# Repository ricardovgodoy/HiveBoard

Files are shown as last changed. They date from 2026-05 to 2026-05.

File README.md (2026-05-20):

# HiveBoard – a Modular Dexterity Benchmark for Industrial Robotics

<p align="center">
    <picture>
  <source media="(prefers-color-scheme: dark)" srcset="Images/HIVEBOARD_logo_dark.png" width="50%">
  <source media="(prefers-color-scheme: light)" srcset="Images/HIVEBOARD_logo_light.png" width="50%">
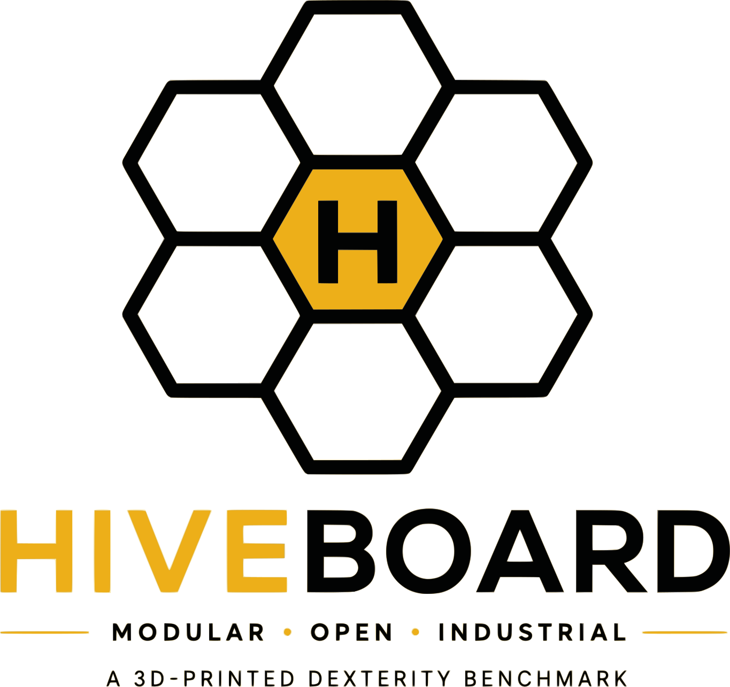
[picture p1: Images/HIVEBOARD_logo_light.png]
Project Logo
  
    </picture>
</p>

Demonstration video: https://youtu.be/kaYB_Oc64nA

## Overview

HiveBoard is an open, modular, and fully 3D-printable dexterity benchmark designed for evaluating industrial robotic manipulation systems. The project focuses on reproducibility, accessibility, and compatibility with both real-world robotic systems and simulation environments.

The platform is designed around three principles:

- **Low-cost reproducibility** using consumer-grade FDM 3D printers
- **Modular task expansion** through interchangeable attachments
- **Simulation-ready assets** for robotics research and sim-to-real workflows

The system consists of a **hexagonal honeycomb base** that accepts interchangeable attachments representing industrial manipulation tasks such as:

- Valves
- Circuit breakers
- Threaded fasteners
- Peg insertion
- Drawer manipulation
- Lock-and-key
- Shock absorber assemblies

All components in this repository are printable in **PLA filament**.

---

## Project Architecture

<p align="center">
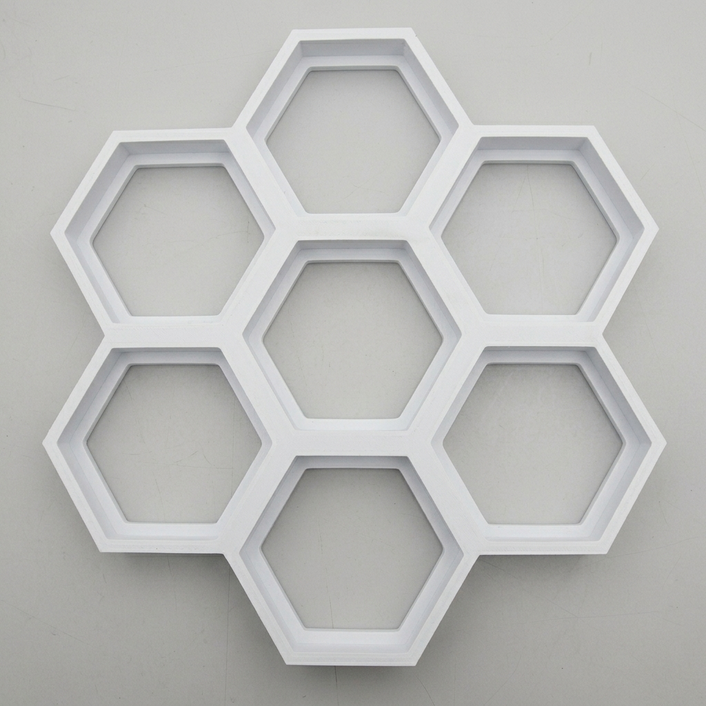
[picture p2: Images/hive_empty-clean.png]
    
</p>

The HiveBoard base contains seven hexagonal cells arranged in a honeycomb pattern. Each attachment uses a standardized press-fit mounting geometry, allowing rapid reconfiguration without screws or fasteners.

This modular architecture enables:

- Fast task swapping
- Difficulty scaling
- Multi-task robotic evaluations
- Easy extension with new attachments

---

## Attachment Categories

### 1. Torque-Based Tasks

<p align="center">
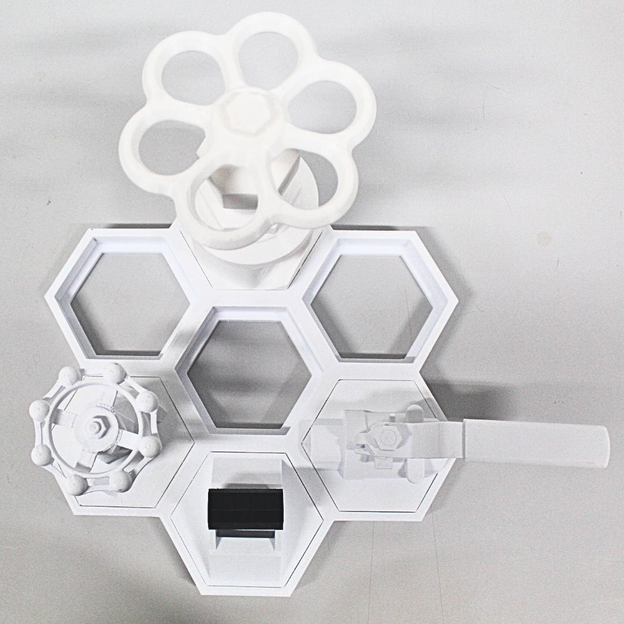
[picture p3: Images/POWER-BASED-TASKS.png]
    
</p>

These tasks evaluate force control and rotational manipulation capabilities.

Included components:

| Attachment | Description |
|---|---|
| Ball Valve | Quarter-turn valve with a lever handle |
| Friction Rings | Snap-on rings (set of four) that increase rotational friction, and therefore torque resistance, on the ball valve |
| Gate Valve (Small) | Compact gate valve with a smaller handwheel |
| Gate Valve (Large) | Larger gate valve with a higher-leverage handwheel |
| Circuit Breaker | Toggle-style industrial breaker |

The friction-ring system gives multiple torque levels on the ball valve without printing additional valves. Each ring sets a different rotational friction.

---

### 2. Precision-Based Tasks

<p align="center">
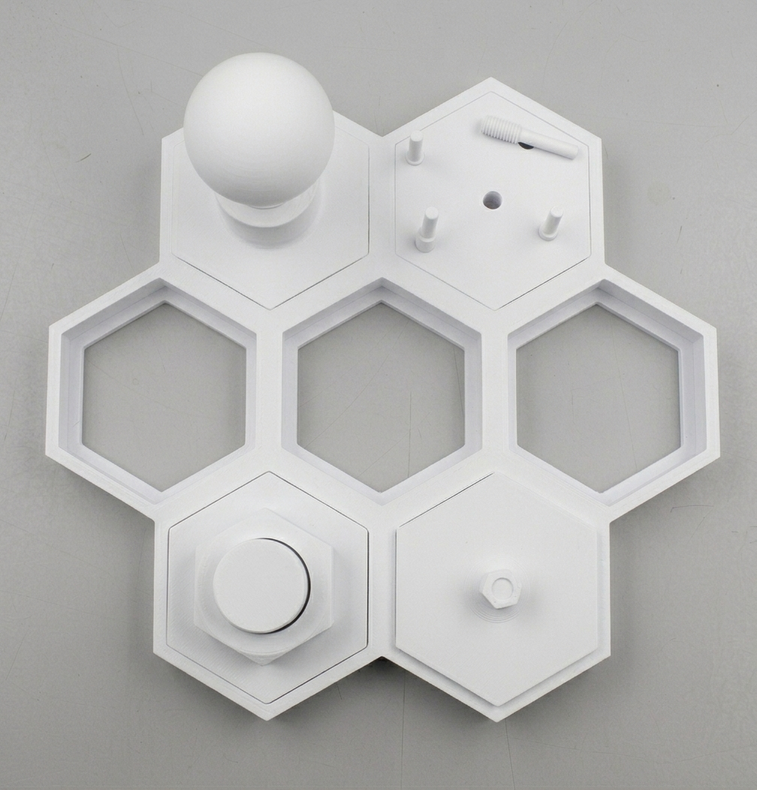
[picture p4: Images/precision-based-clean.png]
    
</p>

These tasks focus on alignment, insertion, and fine manipulation.

Included components:

| Attachment | Description |
|---|---|
| Light Bulb Socket | Threaded bulb-and-socket assembly |
| Thread M8 | Small threaded fastener |
| Thread M30 | Large threaded fastener |
| Peg Insertion Plate | Tight-clearance peg alignment |

These attachments challenge grasp precision and fine alignment.

---

### 3. Composed Assembly Tasks

<p align="center">
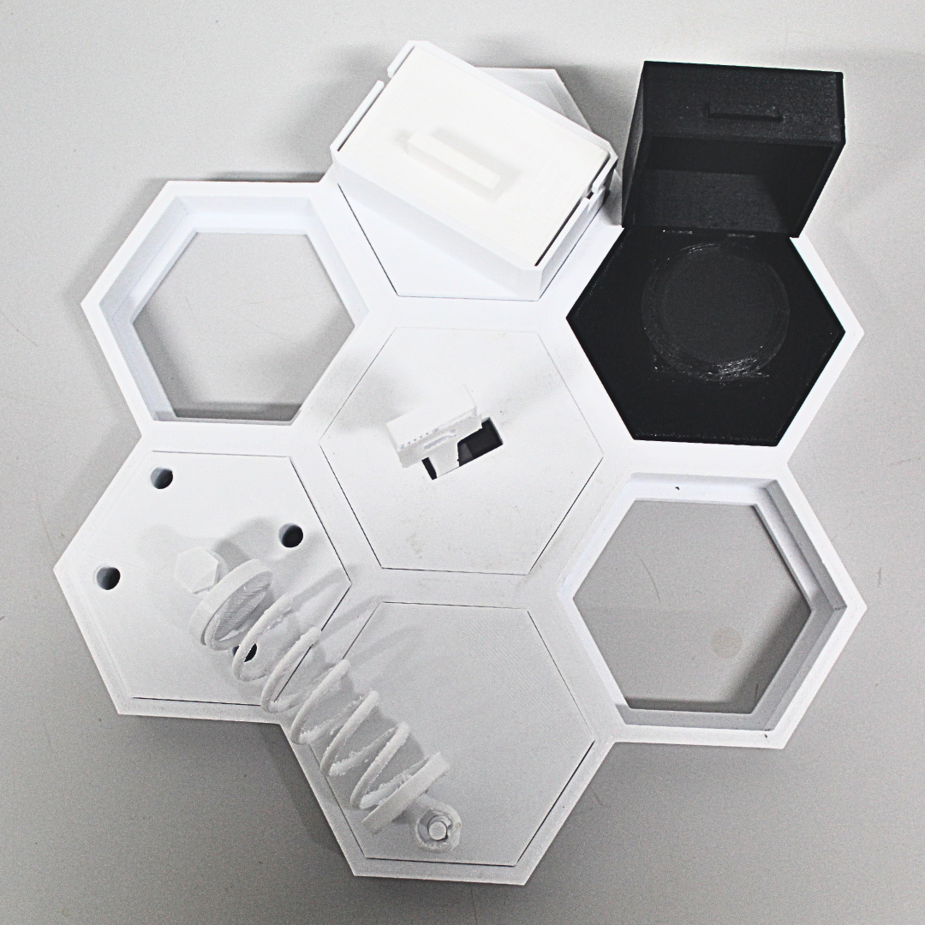
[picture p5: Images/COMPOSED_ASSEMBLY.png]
    
</p>

These tasks involve multiple sequential manipulation stages.

Included components:

| Attachment | Description |
|---|---|
| Hidden Push Button | Hinged cover plus button press |
| Lock and Key | Insertion and rotational unlocking |
| Sliding Drawer | Linear motion manipulation |
| Shock Absorber | Multi-part assembly that occupies two adjacent cells |

The composed tasks allow evaluation of multi-stage manipulation behavior under stage-wise scoring.

---

## Included STL Components

| Category | Part |
|---|---|
| Base System | Hexagonal Honeycomb Base |
| Torque Tasks | Ball Valve |
| Torque Tasks | Friction Rings |
| Torque Tasks | Gate Valve, Small |
| Torque Tasks | Gate Valve, Large |
| Torque Tasks | Circuit Breaker |
| Precision Tasks | Light Bulb Socket |
| Precision Tasks | Thread M8 |
| Precision Tasks | Thread M30 |
| Precision Tasks | Peg Insertion Plate |
| Assembly Tasks | Hidden Button |
| Assembly Tasks | Lock and Key |
| Assembly Tasks | Sliding Drawer |
| Assembly Tasks | Shock Absorber |

---

## Recommended 3D Printing Settings

**Recommended Print Bed Size:** 300 × 300 mm.

The HiveBoard system was designed around consumer-grade FDM printers with a minimum build volume of 300 × 300 mm, allowing the complete honeycomb base and all attachments to be printed without splitting large structural parts. This ensures better dimensional accuracy, improved press-fit consistency between modules, and simpler assembly across different printers and laboratories.

### Standard PLA Profile

| Setting | Value |
|---|---|
| Material | PLA |
| Nozzle Diameter | 0.4 mm |
| Layer Height | 0.20 mm |
| Wall Count | 4 |
| Top Layers | 5 |
| Bottom Layers | 5 |
| Infill | 20–40% |
| Print Speed | 50 mm/s |
| Nozzle Temperature | 200–220°C |
| Bed Temperature | 50–60°C |
| Cooling Fan | 100% |
| Supports | Only where required |
| Adhesion Type | Skirt or Brim |

---

### Recommended Infill Per Part Type

| Part Type | Recommended Infill |
|---|---|
| Base Structure | 20% |
| Mechanical Parts | 25% |
| Torque Components | 30% |
| Threads | 25% |
| Decorative Covers | 15% |

---

### Suggested Print Orientation

| Component Type | Orientation |
|---|---|
| Threads / Screws | Vertical |
| Nuts | Flat |
| Valves | Handle Up |
| Drawer | Flat on largest face |
| Pegs | Vertical |
| Shock Absorber Parts | Sideways |

---

## Simulation Compatibility

Simulation Assets

The HiveBoard project also includes simulation-ready CAD assets suitable for:

- MuJoCo
- PyBullet
- Isaac Sim
- ROS-based simulators

The digital assets contain:

- Joint definitions
- Collision meshes
- Mass properties
- Revolute and prismatic joints
- URDF and USD exports

This enables direct sim-to-real robotics experimentation.

---

## Evaluation Protocol

A reproducible operator-driven protocol is provided for benchmarking grippers, hands, and policies on HiveBoard:

- [`PROTOCOL.md`](Documentation/PROTOCOL.md): the full protocol, including success criteria, per-attachment timeouts, and stage definitions for the composed assembly tasks.
- [`HOW_TO_FILL_TRIALS.md`](Documentation/HOW_TO_FILL_TRIALS.md): column-by-column instructions for the trial logging template.
- [`trials.csv`](Documentation/trials.csv) and [`trials.xlsx`](Documentation/trials.xlsx): pre-populated logging template with one row per trial (5 trials per attachment, 65 rows total). Use the xlsx for filling in (frozen header, dropdowns, color-coded categories); the CSV is provided for scripts.

The protocol prescribes 5 recorded trials per attachment per platform. Operators may control the manipulation system through a teleoperated arm or through a wearable interface or exoskeleton driving a gripper or hand directly. For each trial we record the outcome, completion time, attempts, regrasps, and, for the composed assembly tasks, the highest stage reached within the timeout.

---

## Research Applications

HiveBoard supports:

- Robotic manipulation benchmarking.
- Gripper and dexterous-hand evaluation.
- Teleoperation experiments.
- Wearable-interface and exoskeleton evaluation.
- Reinforcement learning.
- Vision-language-action model evaluation.
- Sim-to-real transfer research.
- Industrial robotics training datasets.

---

## Repository Structure

    /
    ├── STL/             # printable parts
    ├── CAD/             # source CAD files
    ├── Simulation/      # URDF and USD with articulated joints
    ├── Documentation/   # PROTOCOL.md, HOW_TO_FILL_TRIALS.md, trials.csv, trials.xlsx
    ├── Images/          # photographs and renders
    └── README.md

---

## Notes

- All parts are designed for consumer-grade FDM printers.
- PLA is the recommended material for reproducibility.
- Minor sanding can improve threaded part performance.
- Press-fit tolerances depend on printer calibration; print one cell of the base and one attachment first to verify the fit before committing to a full set.
- Functional parts benefit from slower print speeds.

---

## Citation

If you use HiveBoard in research or publications, please cite the project paper:

```
@inproceedings{hiveboard2026,
  title  = {HiveBoard: An Open, Modular, 3D-Printed Dexterity Benchmark for Industrial Robotic Manipulation},
  author = {<authors>},
  booktitle = {<journal>},
  year   = {2026}
}
```

---

## License

This project is intended for research, educational, and prototyping purposes.

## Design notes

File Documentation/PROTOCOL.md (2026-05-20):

# HiveBoard: Data Collection Protocol

This document specifies the data each collaborating laboratory collects to validate HiveBoard, the modular dexterity board. The activity is operator-driven trials, robot-side performance characterization across attachments. Operators may control the manipulation system through a teleoperated arm or through a wearable interface that drives a gripper or hand directly.

The objective is to demonstrate that the board is functional, reproducible, and discriminative across attachments and platforms. The protocol does not rank platforms against each other and does not characterize control interfaces or operators.

**Project resources:**
- Repository (STL, CAD, simulation assets, this protocol, trial logging template): https://github.com/ricardovgodoy/HiveBoard
- Demonstration video (board walk-through and example trials): https://youtu.be/kaYB_Oc64nA

---

## 1. Materials

- One printed HiveBoard base.
- One full set of attachments across all three categories (torque, precision, assembly), including the four-piece friction ring accessory set for the ball valve.
- A manipulation system, consisting of an end-effector (gripper or hand) plus a control interface. The control interface may be:
  - a teleoperated robotic arm with a standard interface (e.g., SpaceMouse, leader arm, VR controller), or
  - a wearable interface or exoskeleton driving the end-effector directly.

## 2. Printing Specifications

The canonical print profile lives in the project README. Summary, for convenience:

- **Material:** PLA, 1.75 mm filament.
- **Nozzle:** 0.4 mm.
- **Layer height:** 0.20 mm.
- **Walls:** 4 perimeters.
- **Top / bottom layers:** 5 / 5.
- **Print speed:** 50 mm/s.
- **Nozzle temperature:** 200--220 °C.
- **Bed temperature:** 50--60 °C.
- **Cooling:** 100%.
- **Adhesion:** skirt or brim.
- **Supports:** only where required.

**Infill, per part type:**

| Part type | Infill |
|---|---|
| Base structure | 20% |
| Mechanical parts | 25% |
| Torque components | 30% |
| Threads | 25% |
| Decorative covers | 15% |

**Print orientation:**

| Component | Orientation |
|---|---|
| Threads / screws | vertical |
| Nuts | flat |
| Valves | handle up |
| Drawer | flat on the largest face |
| Pegs | vertical |
| Shock absorber parts | sideways |

**Post-processing.** Remove stringing and check that mating surfaces seat fully before testing. Minor sanding of threaded surfaces may improve performance when printer calibration produces tight tolerances. If sanding is applied to any attachment, record it in the trial `notes` column.

## 3. Physical Setup

1. Fix the HiveBoard base to a rigid surface within the operator's working volume. The base may be mounted horizontally on a tabletop or vertically on a fixture. Record the orientation used.
2. Insert the attachments into their designated cells. Each attachment seats by press-fit; verify all attachments are fully seated before starting trials.
3. Position the manipulation system so that all attachments are reachable without base repositioning during a trial.
4. Photograph the setup and store the image as `setup.jpg`.

## 4. Trial Procedure

For each `(platform, attachment)` pair:

1. **Familiarization.** Run unrecorded practice trials until completion times stabilize. Record only after three consecutive practice trials complete within 20% of each other or within the timeout, whichever comes first.
2. **Recorded trials.** Run **5 recorded trials** per attachment. The end-effector starts each trial from the same neutral pose for a given platform.
3. **Trial start.** Begin timing when the operator initiates the first commanded motion toward the attachment.
4. **Trial end.** Stop timing when the success criterion is met, when a safety event occurs, or when the timeout is reached.
5. **Reset.** Return the attachment to its starting state between trials. Re-seat the attachment in its cell if displaced.

The ball valve is run as two separate sets of 5 trials: once without the friction ring (`valve_ball`) and once with the ring fitted (`valve_ball_ring`).

No scripted assistance, replanning, or per-trial parameter tuning is permitted during recorded trials. The operator may restart their motion within a trial (this counts as a re-grasp, not a new trial).

## 5. Per-Attachment Success Criteria and Timeouts

**Torque category**

| Attachment | Success criterion | Timeout |
|---|---|---|
| Ball valve | Handle rotated 90° from closed to open | 60 s |
| Ball valve + friction ring | Handle rotated 90° from closed to open with the ring fitted | 90 s |
| Gate valve, small | Stem rotated from fully closed to fully open | 90 s |
| Gate valve, large | Stem rotated from fully closed to fully open | 120 s |
| Circuit breaker | Toggle moved from one state to the other and held | 60 s |

**Precision category**

| Attachment | Success criterion | Timeout |
|---|---|---|
| Light bulb | Bulb fully threaded until seated | 120 s |
| Thread M8 | Bolt fully threaded along available length | 120 s |
| Thread M30 | Bolt fully threaded along available length | 120 s |
| Peg insertion | Free peg fully seated in the empty socket | 120 s |

**Composed assembly category (stage-wise scoring)**

These attachments are scored at sub-task granularity. Record the highest reached stage within the timeout.

| Attachment | Stages | Timeout |
|---|---|---|
| Button | (1) Open the cover (2) Press the button until actuation | 60 s |
| Lock and key | (1) Grasp key (2) Insert key vertically (3) Rotate to unlock | 180 s |
| Drawer | (1) Grasp handle (2) Pull open (3) Push closed | 120 s |
| Shock absorber | (1) Grasp pin (2) Align with hole (3) Insert pin fully | 180 s |

A trial is a full success only if all stages complete within the timeout. Partial completions are recorded by their highest reached stage in the `stage_reached` column.

## 6. Data to Log per Trial

Each trial fills one row of `trials.csv` (template provided alongside this protocol). See `HOW_TO_FILL_TRIALS.md` for column-by-column instructions.

Alongside `trials.csv`, each lab provides:

- `setup.jpg`, photograph of the physical setup.
- `platform.md`, short description of the manipulation system: end-effector (gripper or hand), control interface (teleoperated arm or wearable), and any relevant control mode or calibration notes.

## 7. Submission

Each collaborating lab returns a single archive containing:

- `trials.csv`
- `setup.jpg`
- `platform.md`

### Reproducibility checklist

- [ ] All attachments printed with the specified PLA profile and per-part-type infill.
- [ ] Each attachment seats fully in the base before trials begin.
- [ ] Familiarization completed for every attachment before recording.
- [ ] 5 recorded trials per attachment, all logged in `trials.csv`. The ball valve appears twice, once without the friction ring and once with it.
- [ ] Timeouts enforced as specified.
- [ ] `setup.jpg` and `platform.md` included.
- [ ] No operator names or identifiers in any field.

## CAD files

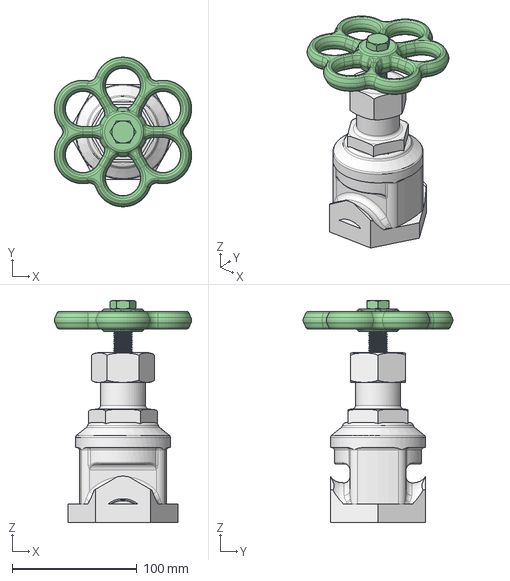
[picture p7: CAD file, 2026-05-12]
CAD/Valves/Gate Valve/High Torque Valve/High_Torque_Valve_Assembly.step
110.0 x 119.9 x 177.8 mm

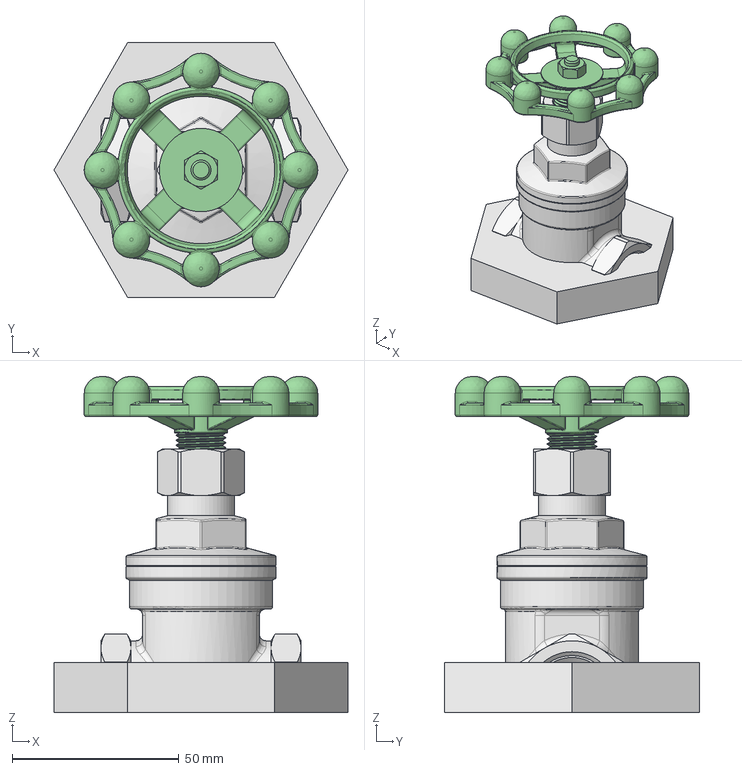
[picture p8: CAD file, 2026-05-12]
CAD/Valves/Gate Valve/Small Valve/Small_Valve_Assembly.step
88.1 x 76.3 x 100.7 mm

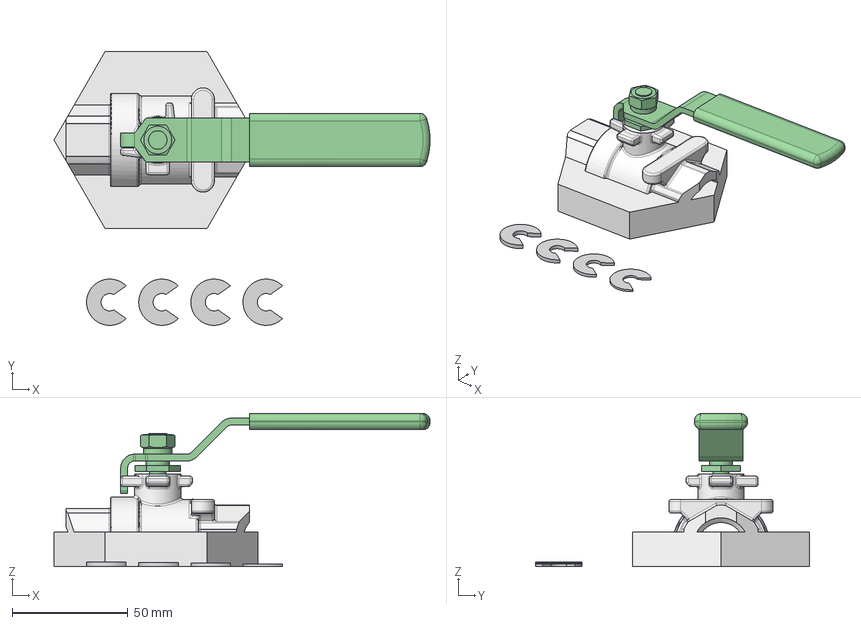
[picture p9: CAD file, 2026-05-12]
CAD/Valves/Lever Valve/Ball Valve/Ball_Valve_Assembly.step
162.3 x 118.1 x 66.1 mm

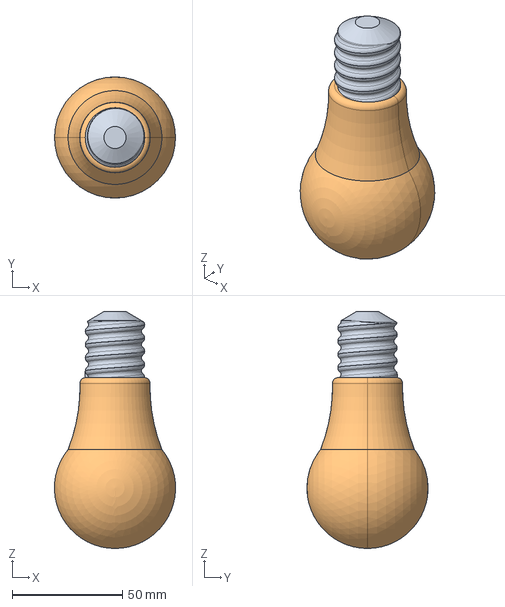
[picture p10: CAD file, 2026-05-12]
CAD/Lamp/Lamp_Assembly.step
55.0 x 55.0 x 107.5 mm

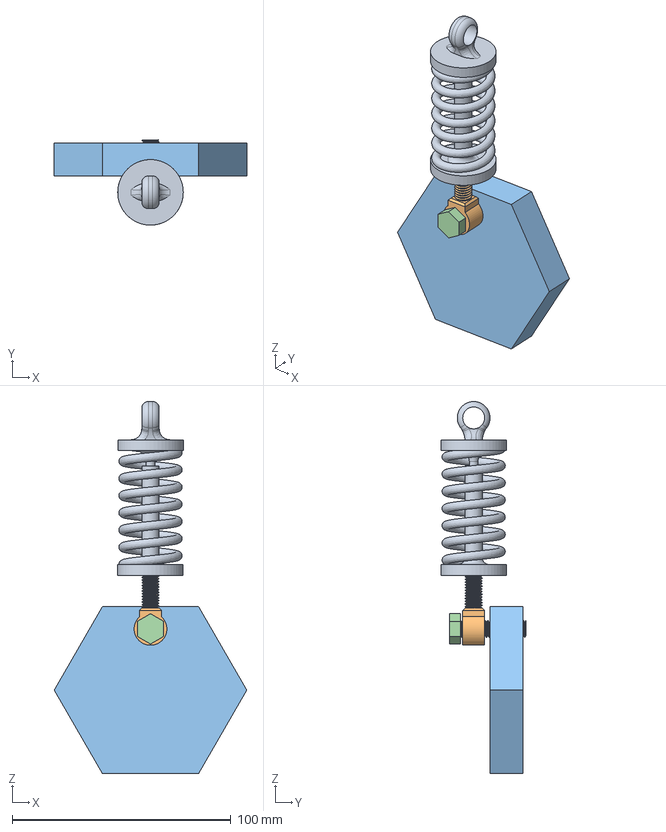
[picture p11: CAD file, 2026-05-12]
CAD/Shock Absorber/Shock_Absorber_Assembly.step
88.1 x 39.0 x 170.2 mm

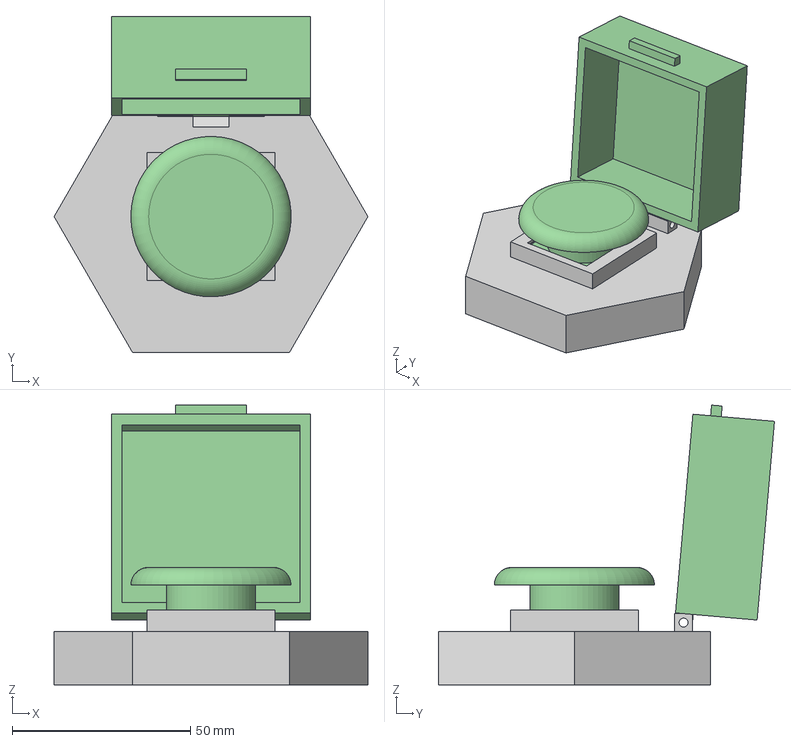
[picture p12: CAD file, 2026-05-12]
CAD/Button/Button_Assembly.step
88.1 x 94.3 x 78.5 mm

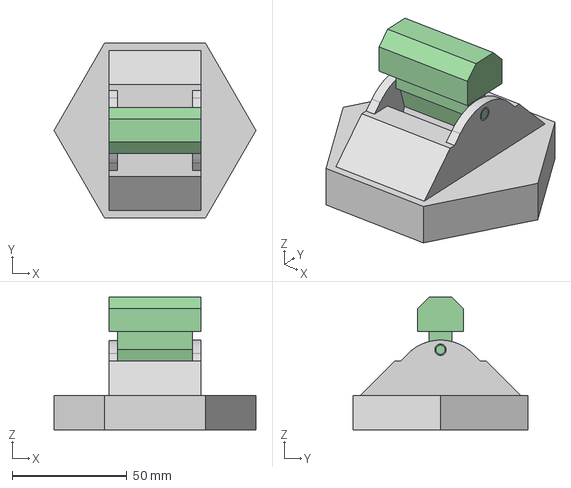
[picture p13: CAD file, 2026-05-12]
CAD/Circuit Breaker/Circuit_Breaker_Assembly.step
88.1 x 76.3 x 58.0 mm

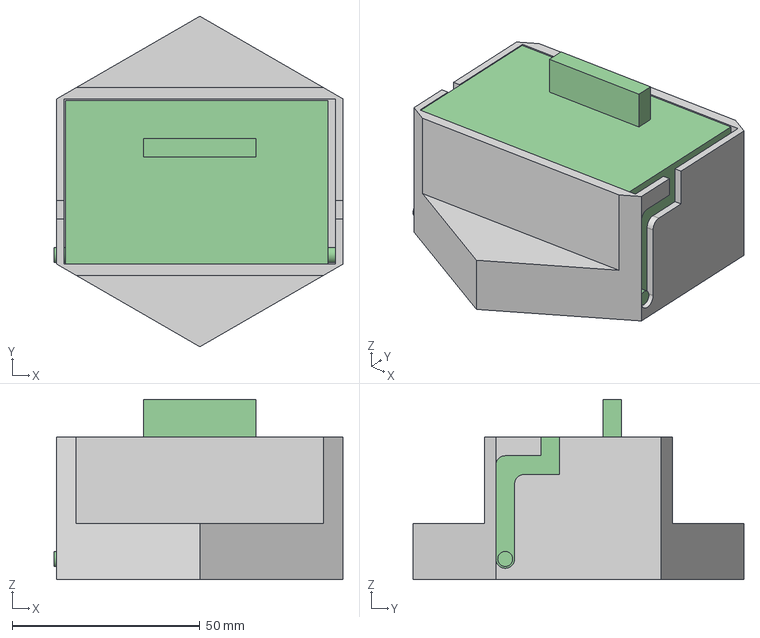
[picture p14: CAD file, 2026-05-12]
CAD/Drawer/Drawer_Assembly.step
77.0 x 88.1 x 48.0 mm

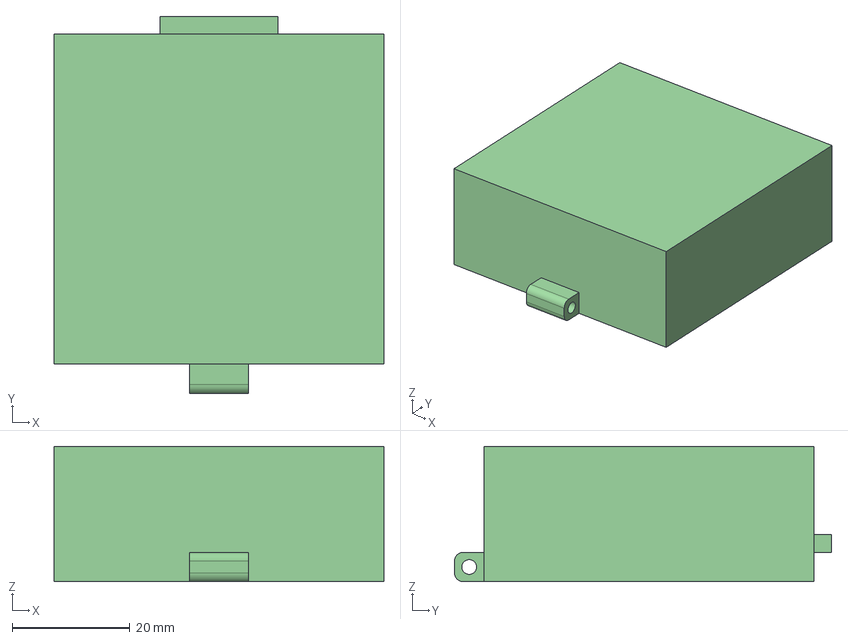
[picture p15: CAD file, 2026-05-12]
CAD/Button/Button_Cover.step
56.0 x 64.0 x 23.0 mm

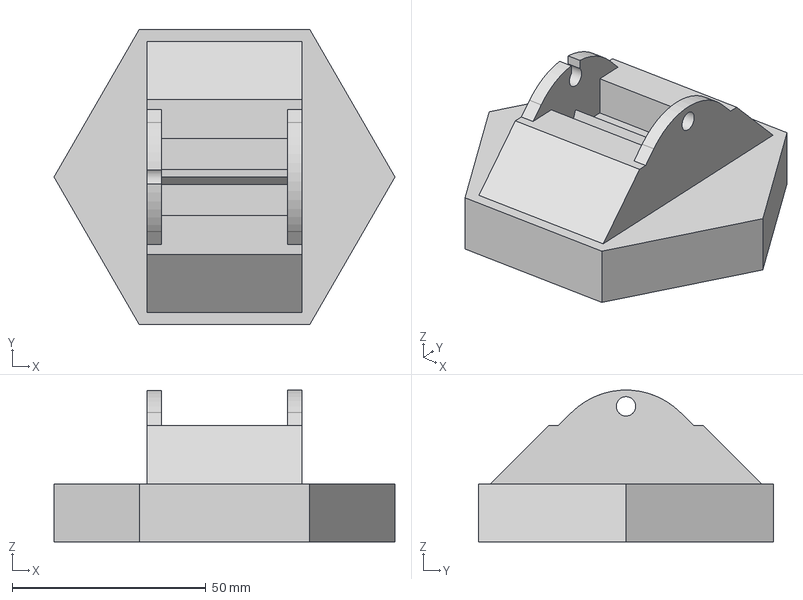
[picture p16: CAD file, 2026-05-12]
CAD/Circuit Breaker/Circuit_Breaker_Base.step
88.1 x 76.3 x 39.2 mm

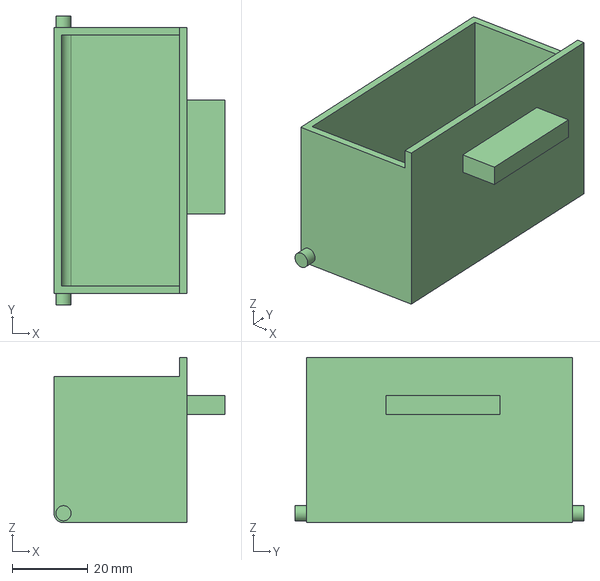
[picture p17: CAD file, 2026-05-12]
CAD/Drawer/Drawer.step
45.0 x 76.0 x 43.5 mm

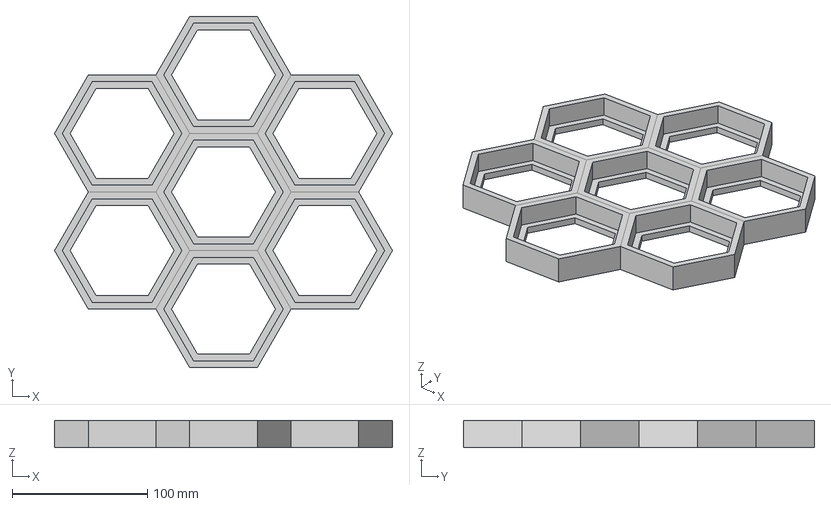
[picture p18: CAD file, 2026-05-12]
CAD/Honeycomb/Honeycomb_Panel.step
250.0 x 259.8 x 20.0 mm

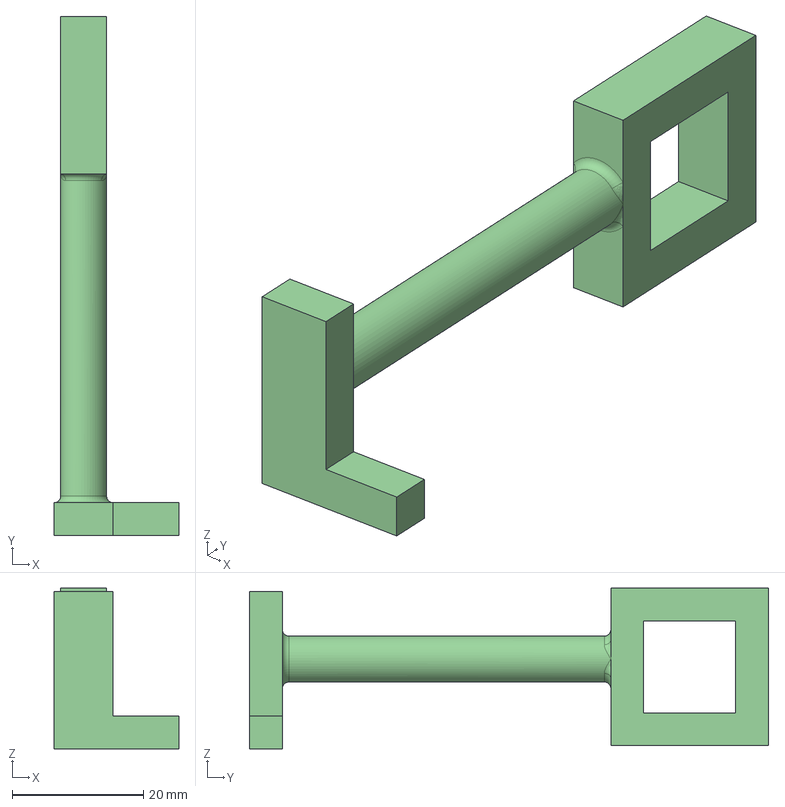
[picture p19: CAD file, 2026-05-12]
CAD/Key/Key.step
19.0 x 79.0 x 24.5 mm

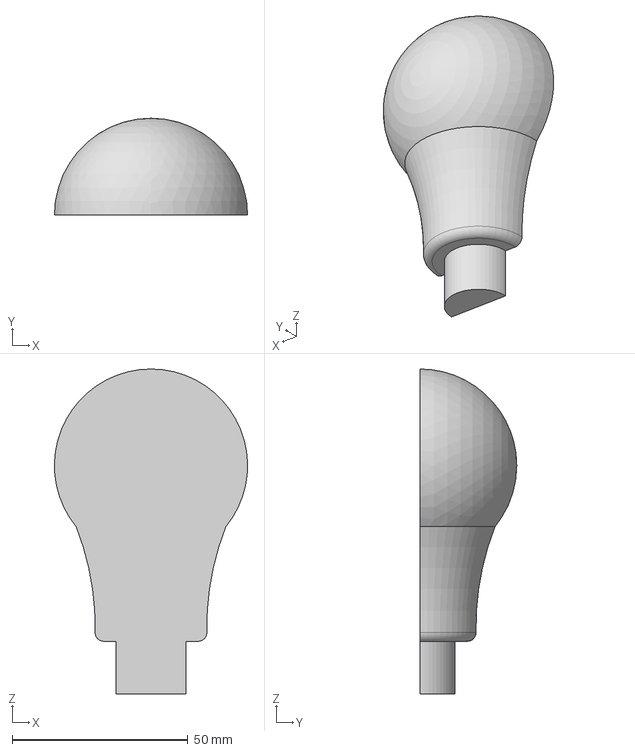
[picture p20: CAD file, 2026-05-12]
CAD/Lamp/Half_Lamp.step
55.0 x 27.5 x 92.5 mm

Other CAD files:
CAD/Button/Button_Base.step
CAD/Circuit Breaker/Circuit_Breaker_Switch.step
CAD/Drawer/Drawer_Base.step
CAD/Honeycomb/Honeycomb.step
CAD/Button/Button.step
CAD/Button/Button_Spring.step
CAD/Key/Key_Base.step
CAD/Lamp/Lamp_Base.step
CAD/Lamp/Lamp_Screw.step
CAD/Shock Absorber/Shock_Absorber.step
CAD/Shock Absorber/Shock_Absorber_Base.step
CAD/Shock Absorber/Shock_Absorber_Pin.step
CAD/Shock Absorber/Shock_Absorber_Screw.step
CAD/Threads/M14 Thread/M14_Nut.step
CAD/Threads/M14 Thread/M14_Screw_Base.step
CAD/Threads/M14 Thread/M14_Test.step
CAD/Threads/M30 Thread/M30_Nut.step
CAD/Threads/M30 Thread/M30_Screw_Base.step
CAD/Threads/M30 Thread/M30_Test.step
CAD/Threads/M8 Thread/M8_Nut.step
CAD/Threads/M8 Thread/M8_Screw_Base.step
CAD/Threads/M8 Thread/M8_Test.step
CAD/Valves/Gate Valve/High Torque Valve/High_Torque_Valve_Base.step
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
